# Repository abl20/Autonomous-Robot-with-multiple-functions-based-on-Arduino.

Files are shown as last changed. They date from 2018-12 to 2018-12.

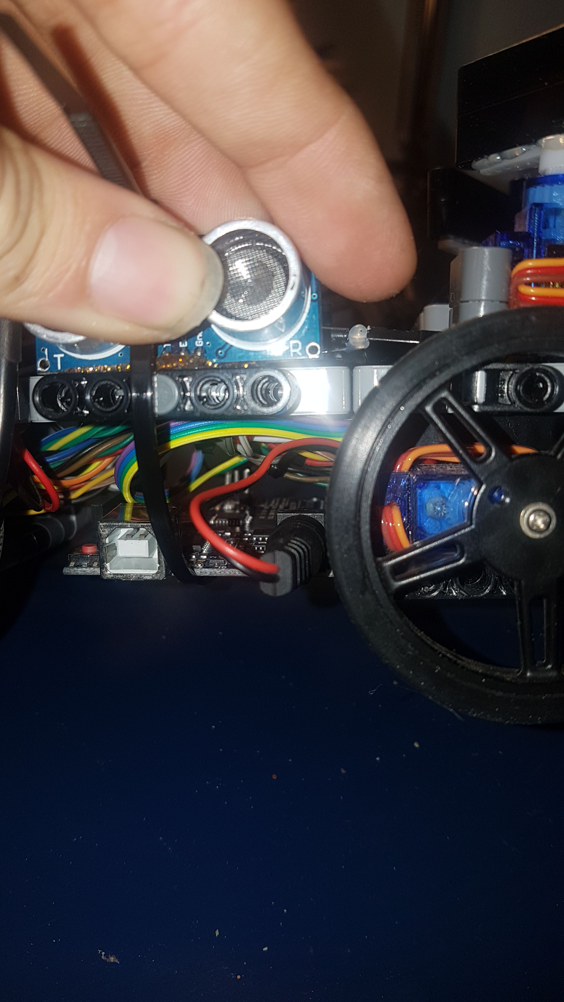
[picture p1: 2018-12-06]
Photos/IMG-20171230-WA0008.jpeg

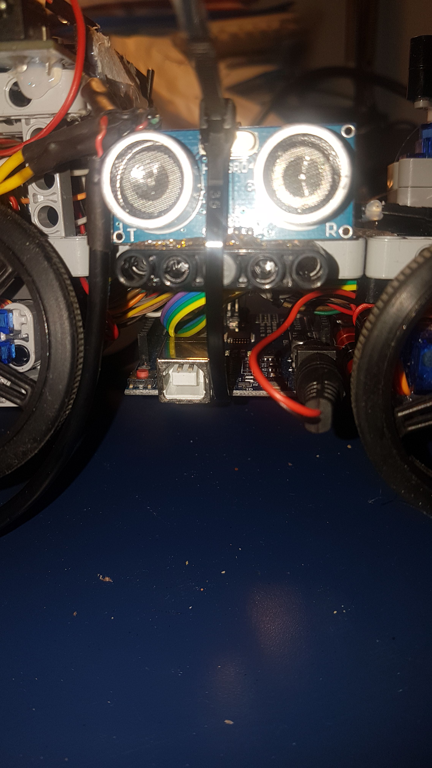
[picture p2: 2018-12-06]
Photos/IMG-20171230-WA0009.jpeg

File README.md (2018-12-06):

Se trata de un robot formado por dos Arduinos: Arduino MEGA y Arduino UNO:

El Arduino MEGA tendrá dos modos seleccionables mediante un interruptor con resistencia de pull-up para evitar así las posibles interferencias. Si se encuentra a nivel alto este interruptor, el robot entrará en modo esquiva-obstáculos, el cuál autónomamente, mediánte los tres sensores ultrsónicos de distancia y los cuatro servomotores de rotacion continua, será capaz de moverse sin interceptar ningun objeto. Si por el contrario el interruptor se encuentra a nivel bajo, el robot se encontrará en el modo control remoto mediante mando infrarrojos. Por medio de este modo, el usuario es capaz de interaccionar con el robot a traves de un mando infrarrojo, pudiendo desplazar el robot en la dirección que se desee y tambien pudiendo accionar las pinzas incorporadas en el robot para desplazar objetos.

El Arduino UNO basará su funcionalidad en base a la conexión de un módulo Bluetooth, al cual se le enviará desde un teléfono móvil, equipado con esta tecnología, las funciones a realizar. Entre ellas estara el control de dos matrices led 8x8 en las cuales aparecerá un texto en scrolling y diversas figuras, un buzzer que será posible seleccionar la canción a reproducir y 2 led’s (uno rojo y otro azul) que se combinaran con el buzzer (simulando el sonido de una sirena) para hacer un modo policía.

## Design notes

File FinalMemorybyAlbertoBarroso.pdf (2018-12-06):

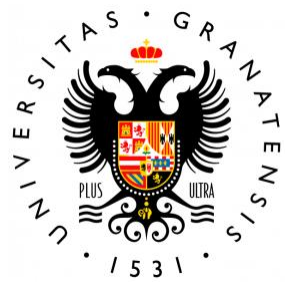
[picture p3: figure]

# ROBOT BASADO EN ARDUINO

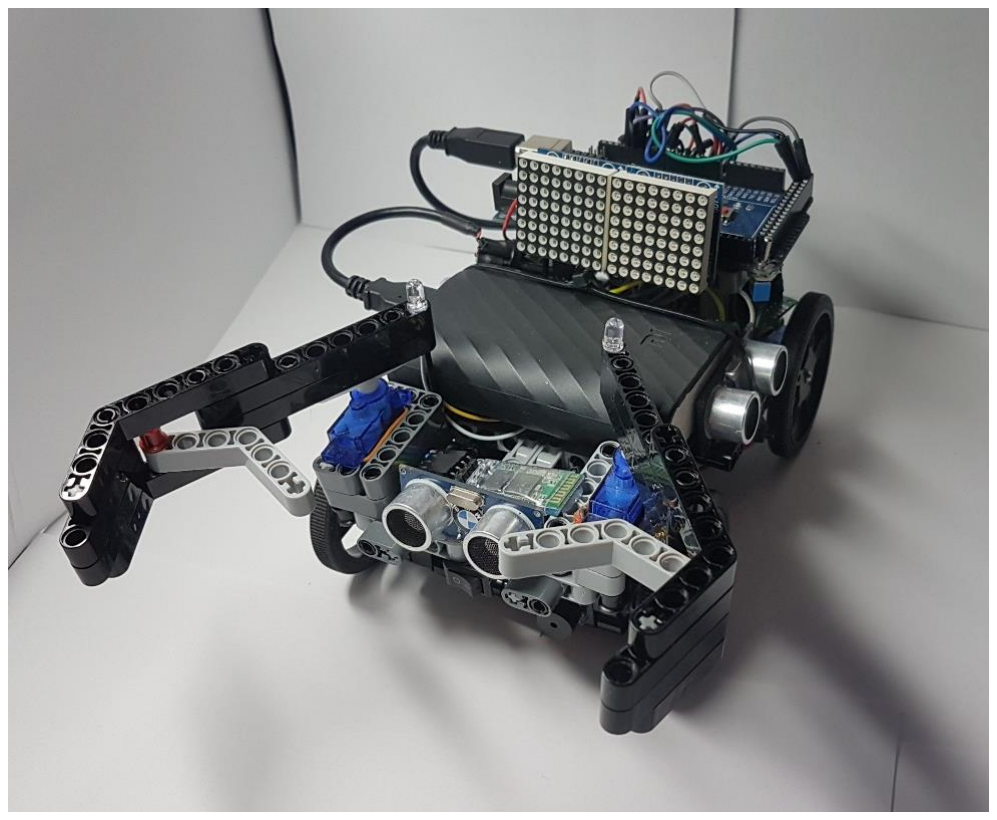
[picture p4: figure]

INGENIERÍA ELECTRÓNICA INDUSTRIAL

ALBERTO BARROSO LÓPEZ

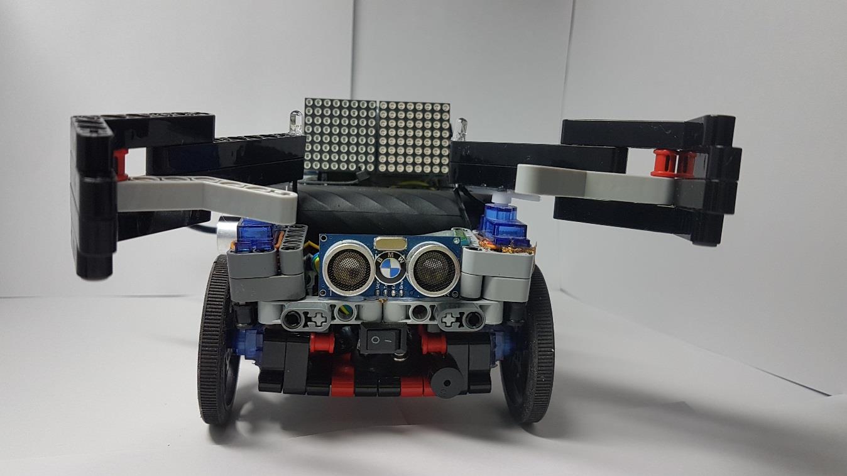
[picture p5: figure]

Pá giná 1

# INFORME DEL PROYECTO

BREVE DESCRIPCIÓN DEL PROPÓSITO DEL PROYECTO

Se trátá de un robot formádo por dos Arduinos: Arduino MEGA y Arduino UNO.

- El Arduino MEGA tendrá dos modos seleccionábles mediánte un interruptor con resistenciá de pull-up párá evitár ásí lás posibles interferenciás. Si se encuentrá á nivel álto este interruptor, el robot entrárá en modo esquiva-obstáculos, el cuál áuto nomámente, mediánte los tres sensores ultráso nicos de distánciá y los cuátro servomotores de rotácio n continuá, será cápáz de moverse sin interceptár ningu n objeto. Si por el contrário el interruptor se encuentrá á nivel bájo, el robot se encontrárá en el modo control remoto mediante mando infrarrojos. Por medio de este modo, el usuário es cápáz de interáccionár con el robot á tráve s de un mándo infrárrojo, pudiendo desplázár el robot en lá direccio n que se desee y támbie n pudiendo áccionár lás pinzás incorporádás en el robot párá desplázár objetos.
- El Arduino UNO básárá su funcionálidád en báse á lá conexio n de un mo dulo Bluetooth, ál cuál se le enviárá desde un tele fono mo vil, equipádo con está tecnologí á, lás funciones á reálizár. Entre ellás estárá el control de dos mátrices led 8x8 en lás cuáles ápárecerá un texto en scrolling y diversás figurás, un buzzer que será posible seleccionár lá cáncio n á reproducir y 2 led’s (uno rojo y otro ázul) que se combinárán con el buzzer (simulándo el sonido de uná sirená) párá hácer un modo policía.

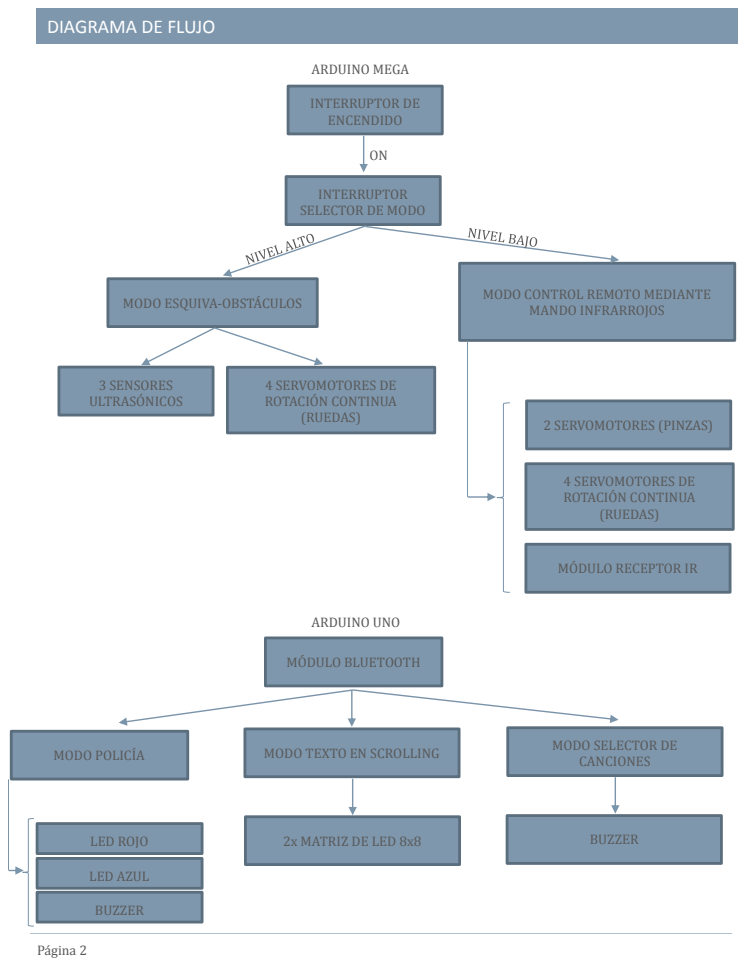
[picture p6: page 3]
ARDUINO MEGA; ARDUINO UNO; 3 SENSORES ULTRASO NICOS; 4 SERVOMOTORES DE ROTACIO N CONTINUA (RUEDAS); INTERRUPTOR DE ENCENDIDO; MANDO INFRARROJOS; 2 SERVOMOTORES (PINZAS); MODO POLICI A; LED ROJO; LED AZUL; BUZZER

DIAGRAMA DE FLUJO

INTERRUPTOR
SELECTOR DE MODO

MODO CONTROL REMOTO MEDIANTE

MODO ESQUIVA-OBSTA CULOS

MO DULO RECEPTOR IR

MO DULO BLUETOOTH

MODO SELECTOR DE
CANCIONES

MODO TEXTO EN SCROLLING

2x MATRIZ DE LED 8x8

MATERIALES EMPLEADOS Y PRESUPUESTO

CANTIDAD | DESCRIPCIÓN | PRECIO UNIDAD | PRECIO TOTAL
1 | ARDUINO UNO | 3,10€ | 3,10€
1 | ARDUINO MEGA | 6,25€ | 6,25€
2 | MATRIZ LED 8X8 + CONTROLADOR MAX7219 | 1,30€ | 2,60€
4 | SERVOMOTOR DE ROTACIO N CONTINUA (POLOLU-1053) | 4,90€ | 19,60€
2 | PACK 2 RUEDAS PARA SERVOMOTOR ROTACIO N CONTINUA (POLOLU-1420) | 7,95€ | 15,90€
2 | SERVOMOTOR TOWER PRO 9G (SG90) | 0,98€ | 1,96€
3 | SENSOR DE DISTANCIA ULTRASO NICO (HC-SR04) | 0,90€ | 2,70€
1 | MODULO BLUETOOTH (HC-06) | 2,70€ | 2,70€
1 | BUZZER | 0,20€ | 0,20€
1 | LED AZUL | 0,20€ | 0,20€
1 | LED ROJO | 0,20€ | 0,20€
1 | RESISTENCIA PULL-UP 20KΩ 1/4W | 0,05€ | 0,05€
1 | INTERRUPTOR ON/OFF | 0,30€ | 0,30€
1 | PLACA PERFORADA 8cmx2cm | 0,25€ | 0,25€
2 | TIRA DE 24 PINES | 0,12€ | 0,24€
1 | POWERBANK XIAOMI 5V 10.000mAh | 15€ | 15€
1 | MU LTIPLES PIEZAS LEGO PARA ESTRUCTURA DEL ROBOT | 14,20€ | 14,20€
47 | CABLES DE CONEXIO N | 0,03€ | 1,41€
TOTAL: 86,86€

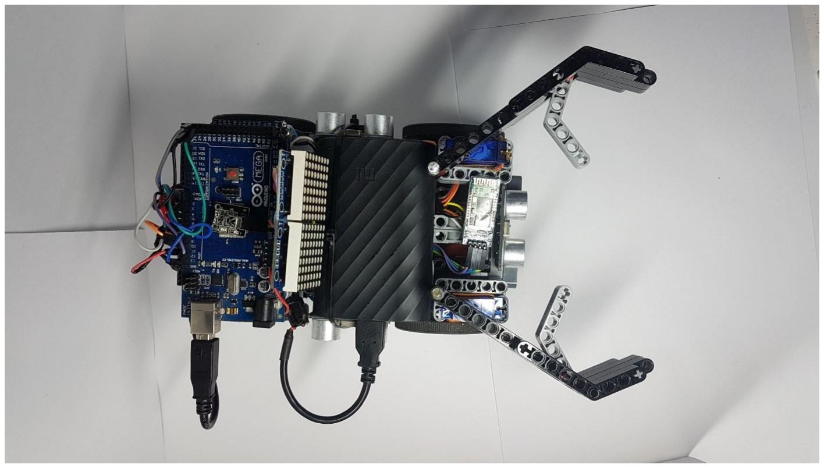
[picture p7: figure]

PROBLEMAS Y SOLUCIONES. OPTIMIZACIONES.

A lo lárgo del proyecto se hán encontrádo mu ltiples problemás como, por ejemplo, debido ál grán nu mero de sensores/áctuádores instáládos en el robot, todos estos necesitán uná álimentácio n á 5V y GRND. En totál 10 sensores/áctuádores, teniendo solo 2 pines de 5V y 2 pines de GRND en el Arduino, ápárte de su limitácio n de consumo má ximo de 500mA. Debido á esto, se decidio fábricár uná plácá de álimentácio n con 5V y GRND directos á lá báterí á powerbánk de 10.000mAh, solucioná ndose dicho problemá.

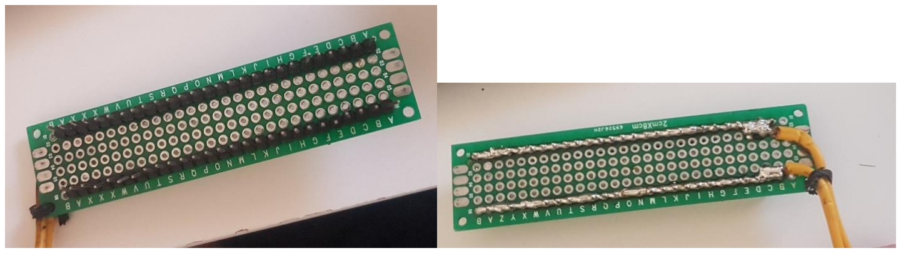
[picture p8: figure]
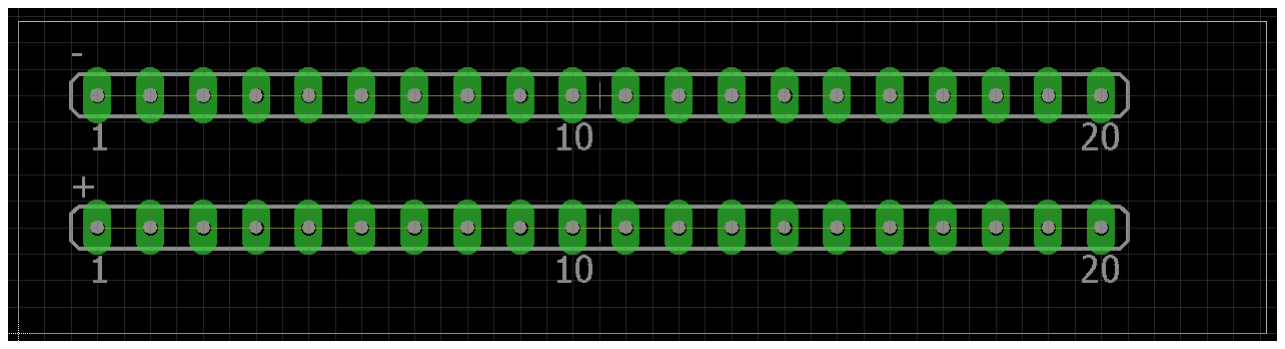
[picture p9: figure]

En esta imagen se muestra el diseño de la placa de alimentación realizado con el programa EAGLE PCB 7.3.

Támbie n se há procedido á optimizár el co digo de prográmá mediánte lá creácio n de mu ltiples funciones y lá modificácio n de librerí ás, con el objetivo de eliminár de dichás librerí ás informácio n que no se fuerá á utilizár.
Lá librerí á utilizádá párá los protocolos IR, fue optimizádá párá que solo cárgárá el protocolo NEC, áhorrándo un grán porcentáje de memoriá en el Arduino.

Librería cargando todos los protocolos.

Librería cargando únicamente el protocolo NEC.

Como se puede observár el sketch utilizárí á 6.634 bytes menos, un 21% menos de uso de lá memoriá.

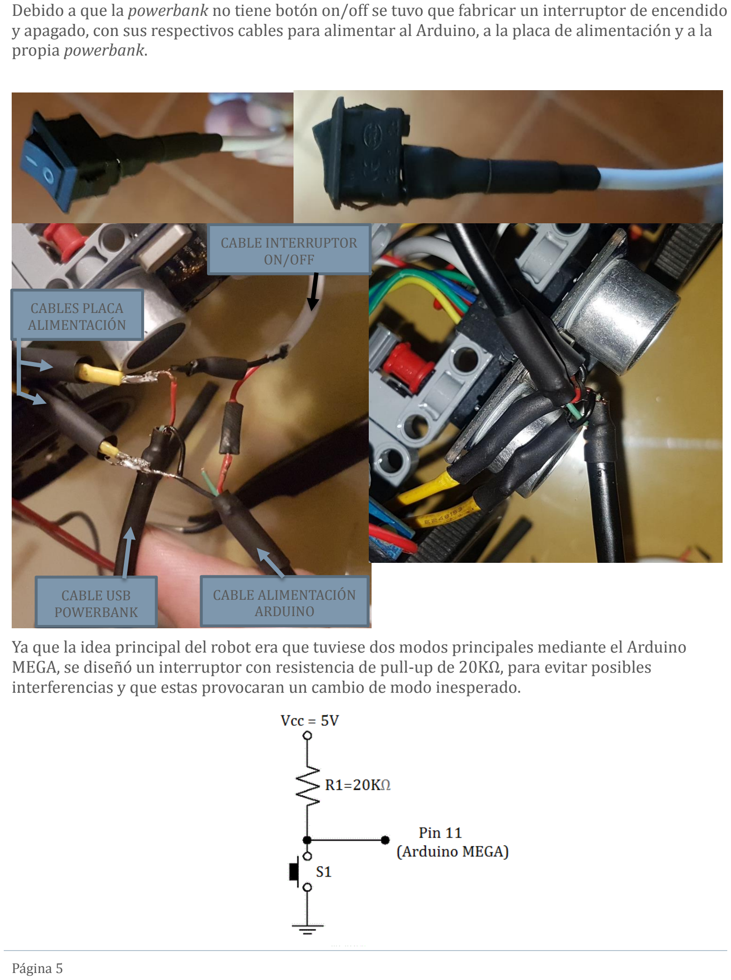
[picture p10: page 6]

Debido á que lá powerbank no tiene boto n on/off se tuvo que fábricár un interruptor de encendido y ápágádo, con sus respectivos cábles párá álimentár ál Arduino, á lá plácá de álimentácio n y á lá propiá powerbank.

+++

Yá que lá ideá principál del robot erá que tuviese dos modos principáles mediánte el Arduino MEGA, se disen o un interruptor con resistenciá de pull-up de 20KΩ, párá evitár posibles interferenciás y que estás provocárán un cámbio de modo inesperádo.

CABLE INTERRUPTOR
ON/OFF

CABLE ALIMENTACIO N
ARDUINO

CABLE USB
POWERBANK

CABLES PLACA
ALIMENTACIO N

Por u ltimo, ál usár el protocolo NEC se encontro un problemá yá que dicho protocolo es especiál cuándo se dejá pulsádo un boto n ininterrumpidámente. Esto supuso un problemá yá que dejándo pulsádo el boto n ‘1’, el boto n ‘2’ o cuálquier boto n, enviábá el mismo identificádor (0xFFFFFFFF). Debido á que el principál objetivo del mándo infrárrojo erá tener un movimiento fluido ál dejár pulsádo cuálquier boto n de direccio n, se utilizo uná nuevá váriáble que guárdáse el válor del
u ltimo válor recibido por infrárrojos y lo compárárá ál nuevo recibido. En cáso de que recibiese el válor del botón pulsado continuamente (0xFFFFFFFF), se reescribirí á con el válor ánterior.

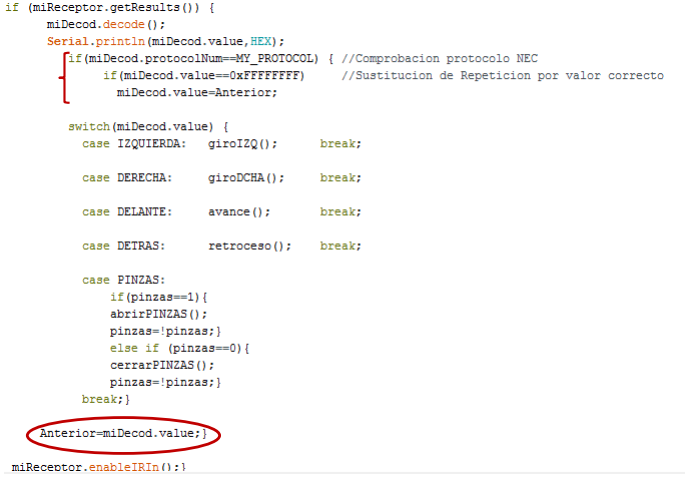
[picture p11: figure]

ESQUEMÁTICO DEL HARDWARE

El esquemá tico del hárdwáre se há reálizádo mediánte el prográmá Proteus 8, en dos ficheros sepárádos yá que el robot es controládo por dos Arduinos (ficheros ádjuntádos en el rár).

## ARDUINO MEGA

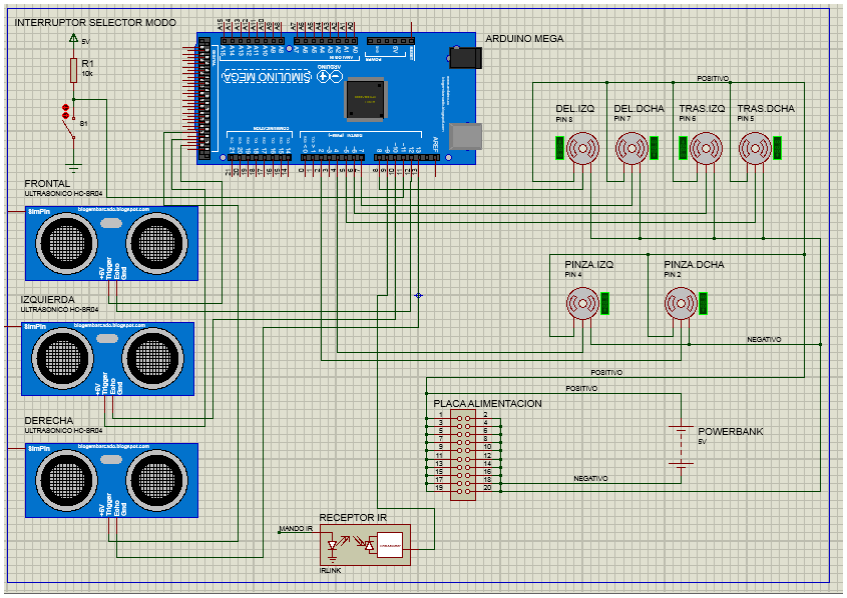
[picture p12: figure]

## ARDUINO UNO

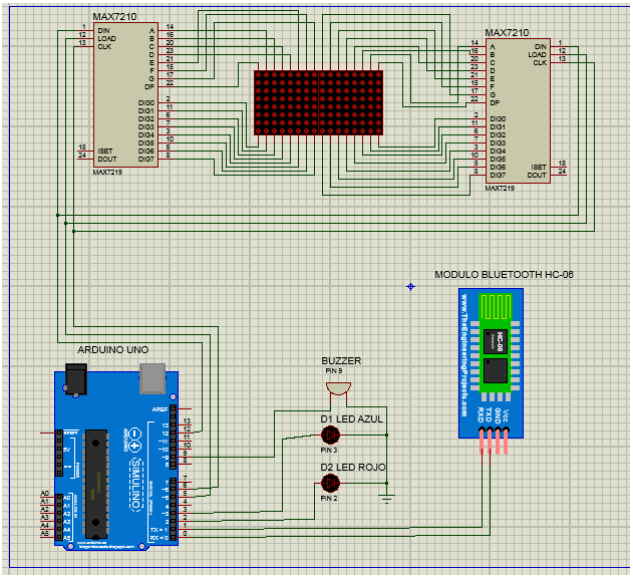
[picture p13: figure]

CÓDIGO FUENTE COMENTADO

## Código ARDUINO MEGA

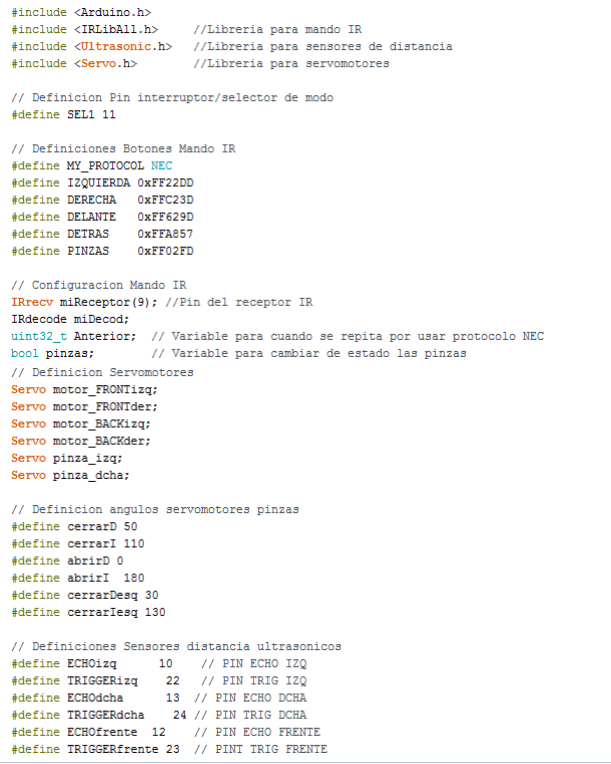
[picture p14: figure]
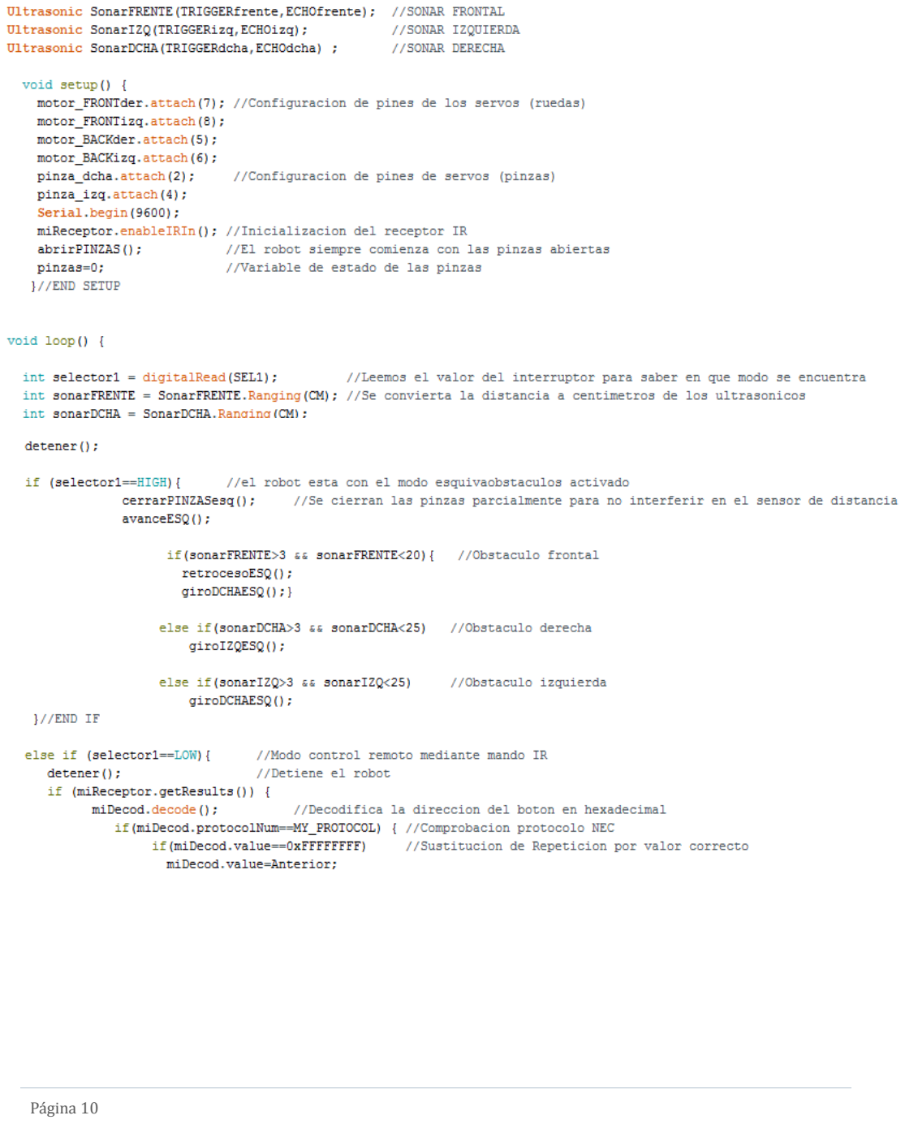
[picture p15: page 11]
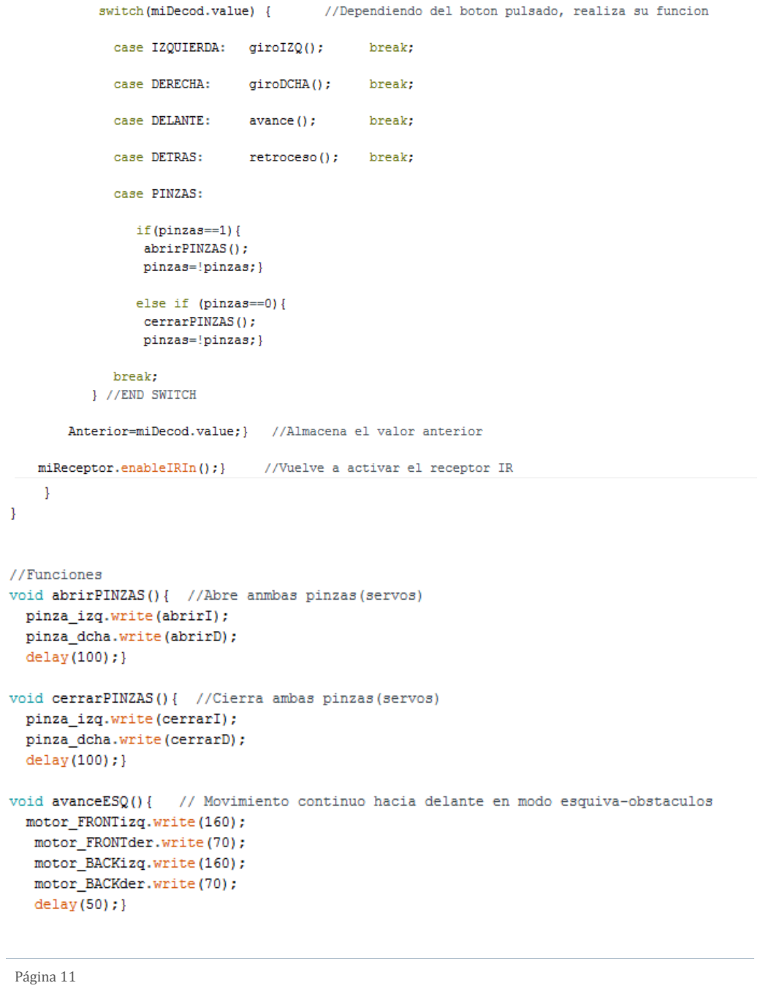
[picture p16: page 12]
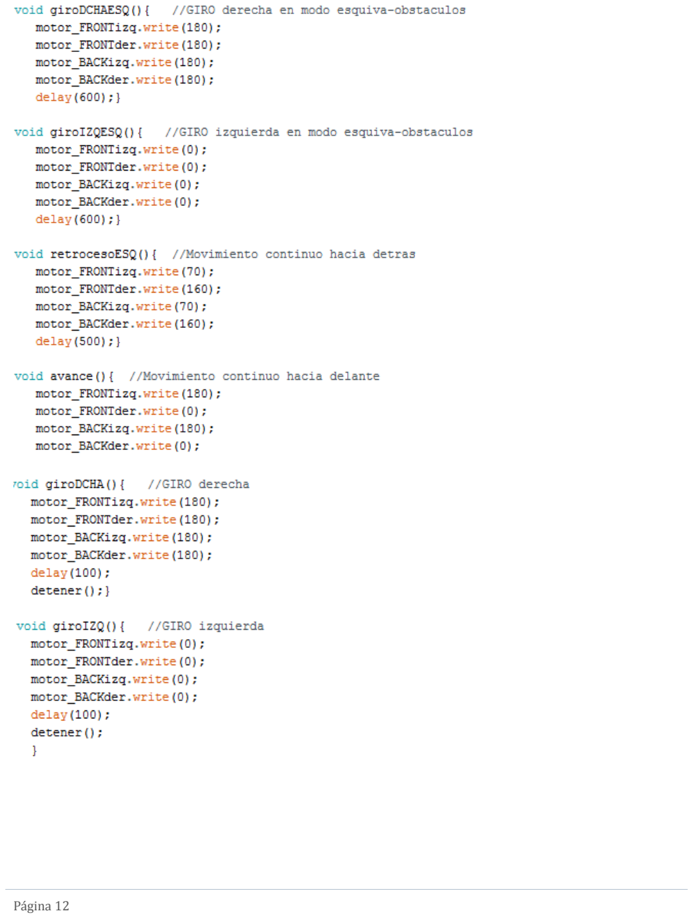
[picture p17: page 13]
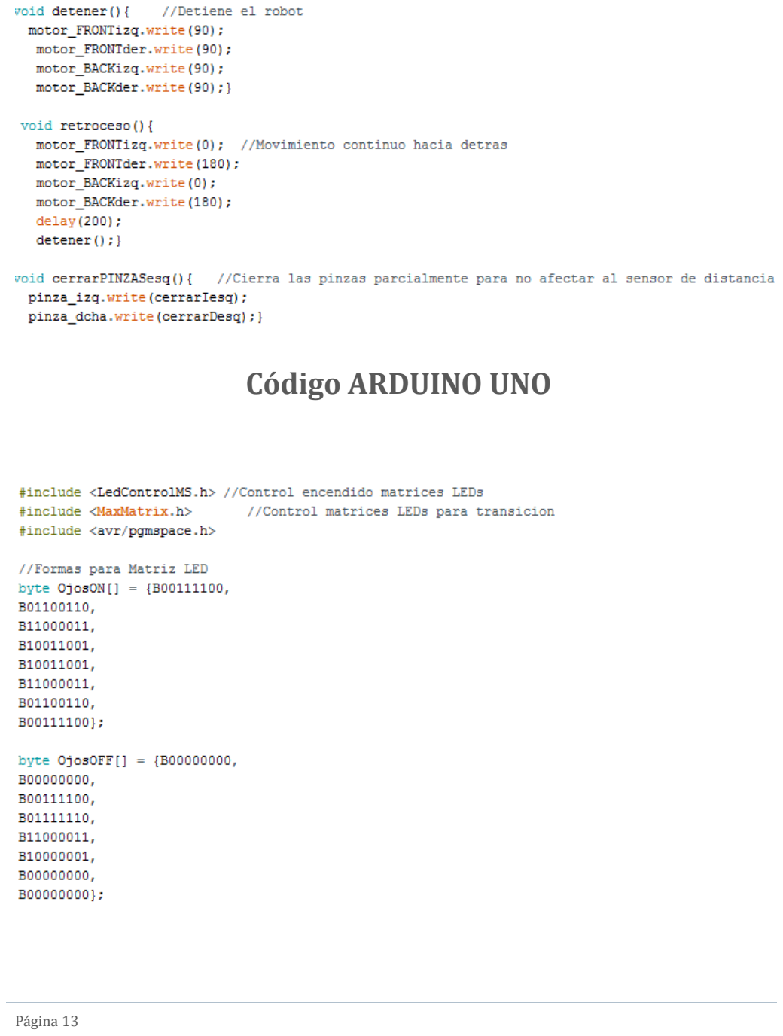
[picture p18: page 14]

## Código ARDUINO UNO

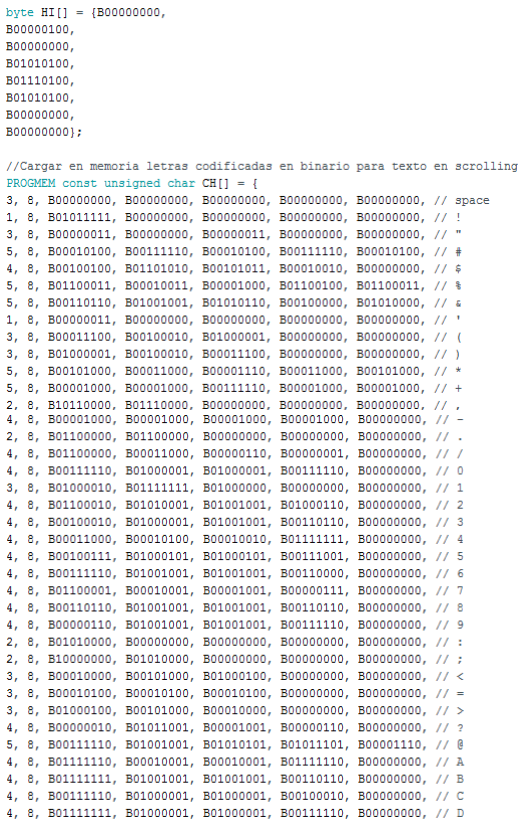
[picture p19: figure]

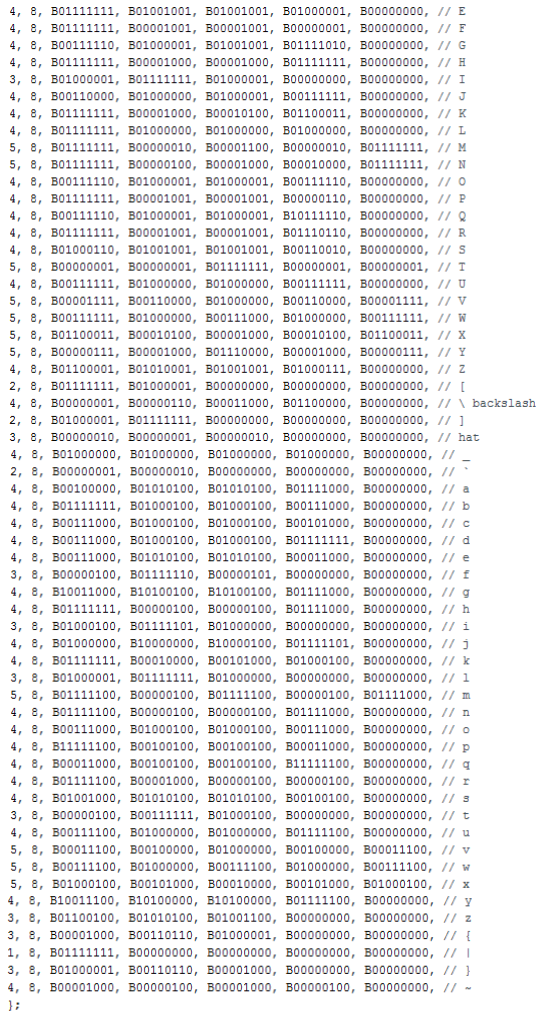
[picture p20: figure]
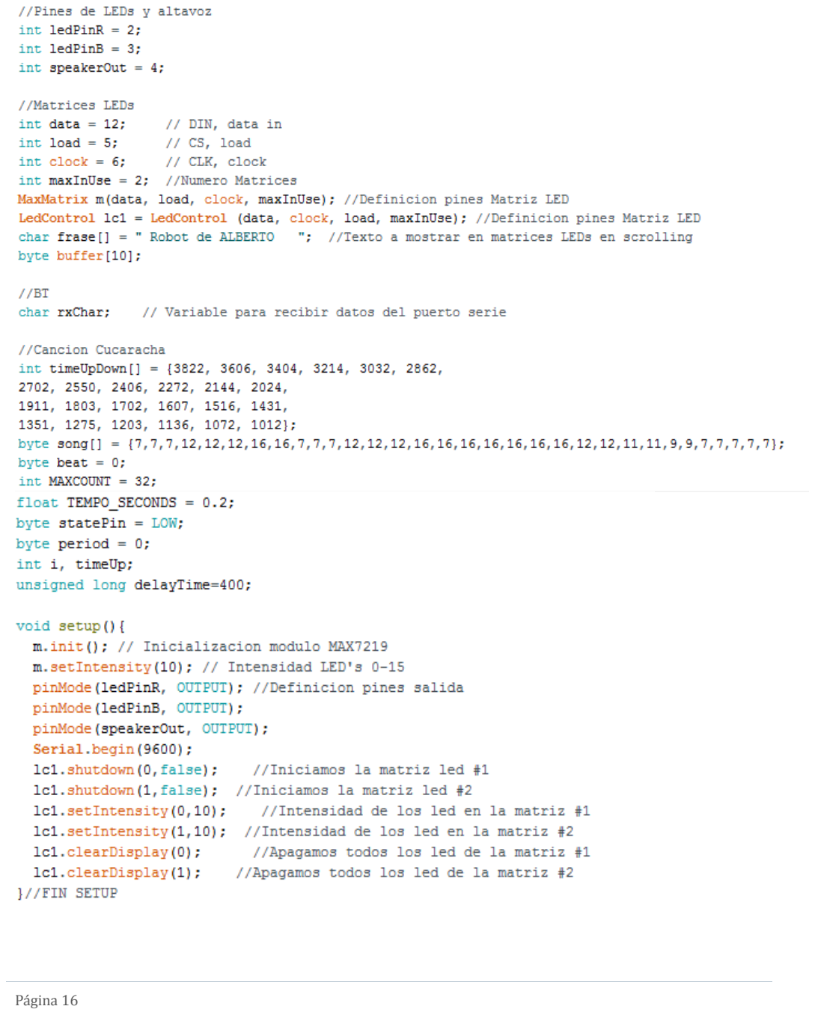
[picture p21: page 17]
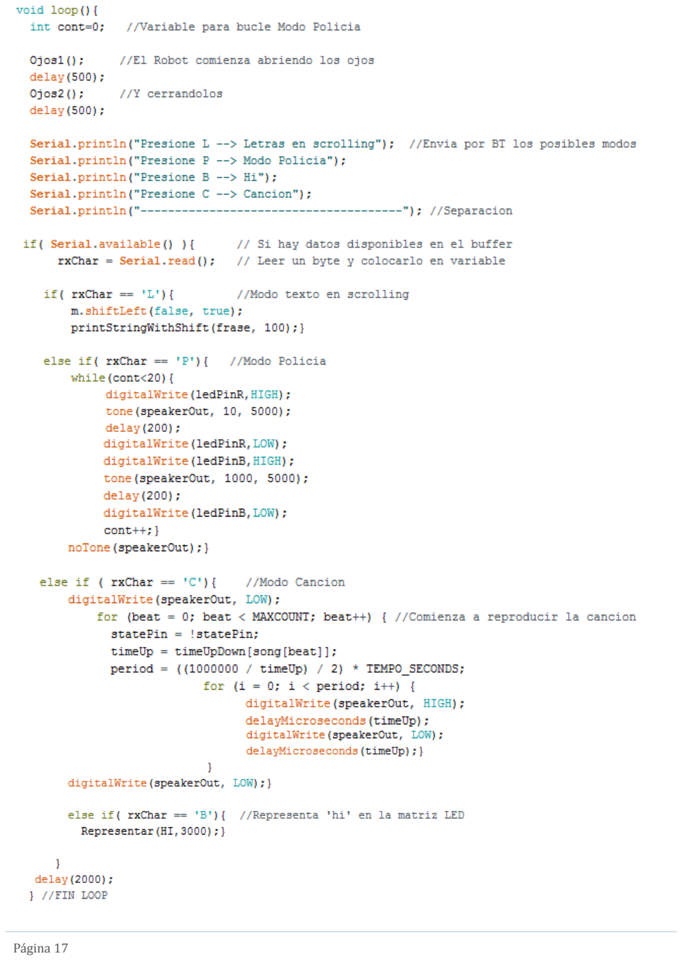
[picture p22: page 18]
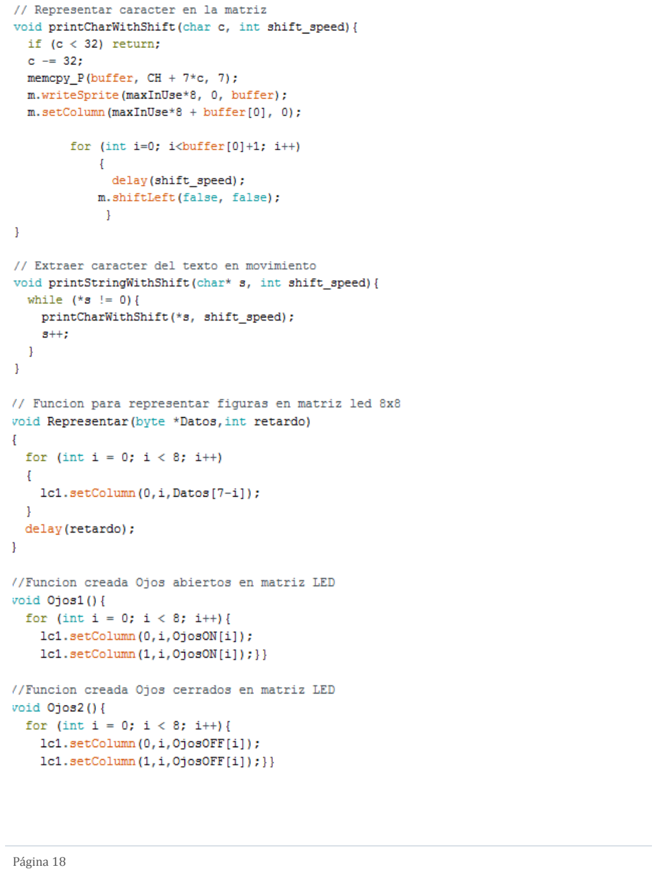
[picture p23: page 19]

BIBLIOGRAFÍA O ENLACES EMPLEADOS

Generador online código matriz 8x8 LED HEX/BINARY para ARDUINO: https://www.riyas.org/2013/12/onlineled-matrix-font-generator-with.html (https://www.riyas.org/2013/12/online-led-matrix-font-generator-with.html)

Librería para Arduino del módulo Ultrasonic Ranging HC-SR04: http://www.ardublog.com/library-for-arduinoultrasonic-ranging-hc-sr04/ (http://www.ardublog.com/library-for-arduino-ultrasonic-ranging-hc-sr04/)

Servomotor Arduino tutorial de programación: https://programarfacil.com/tutoriales/fragmentos/servomotorcon-arduino/ (https://programarfacil.com/tutoriales/fragmentos/servomotor-con-arduino/)

Controlar un servo de rotación continua con Arduino: https://www.luisllamas.es/controlar-un-servo-derotacion-continua-con-arduino/ (https://www.luisllamas.es/controlar-un-servo-de-rotacion-continua-con-arduino/)

Módulo BlueTooth HC-06 Algunos conceptos básicos de BlueTooth: https://www.prometec.net/bt-hc06/

Matrices LED de 8×8 con Arduino y MAX7219: https://www.minitronica.com/matrices-led-8x8-arduino-max7219/

Scrolling con MAX7219. Desplazamiento lateral de mensajes en el display: https://www.prometec.net/scrollmax7219/ (https://www.prometec.net/scroll-max7219/)

Reproducir sonidos con Arduino y un buzzer pasivo o altavoz: https://www.luisllamas.es/reproducir-sonidosarduino-buzzer-pasivo-altavoz/ (https://www.luisllamas.es/reproducir-sonidos-arduino-buzzer-pasivo-altavoz/)

Prácticas de Código Abierto. La Cucaracha con el Arduino: http://codigoabierto.geografias.org/?p=113

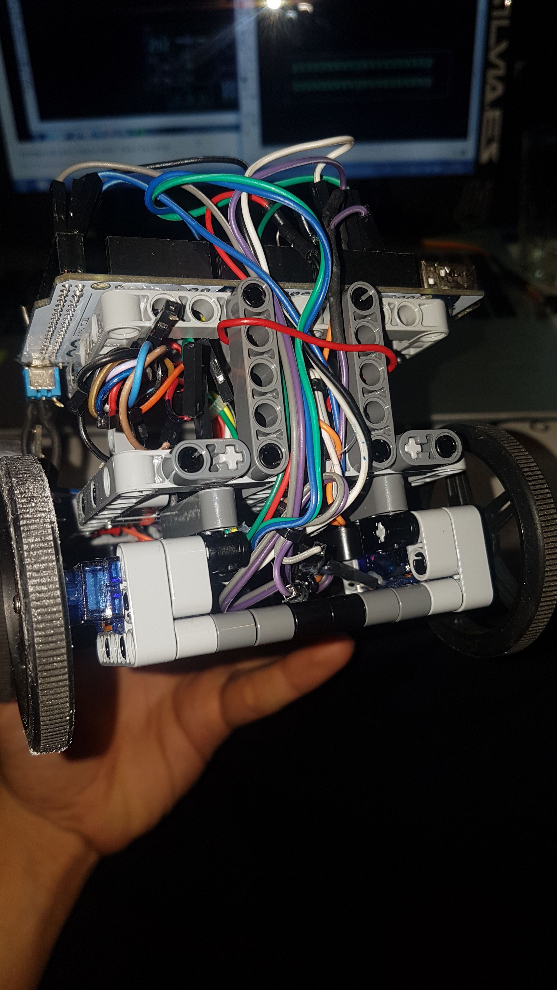
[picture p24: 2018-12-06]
Photos/cables2.jpeg

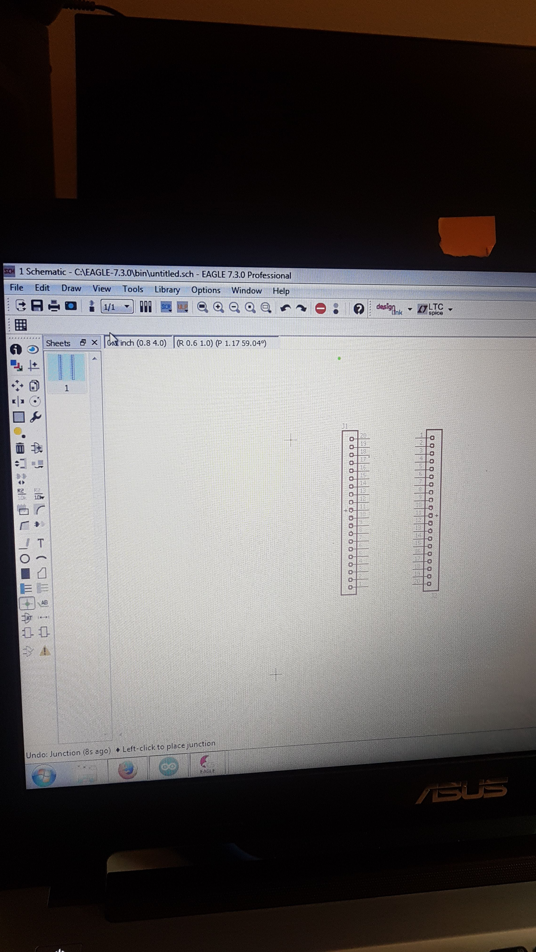
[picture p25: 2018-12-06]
Photos/IMG-20171112-WA0050.jpeg

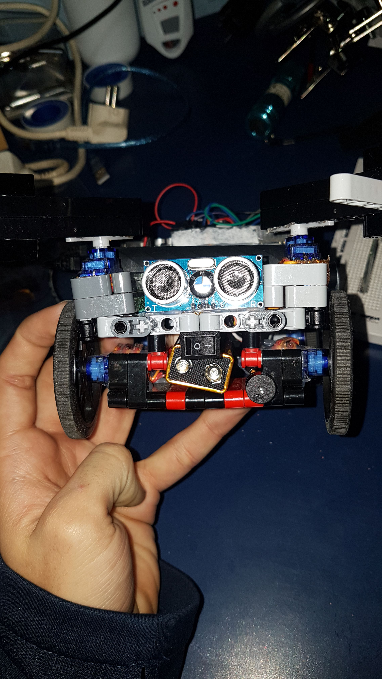
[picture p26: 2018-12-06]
Photos/IMG-20171226-WA0030.jpeg

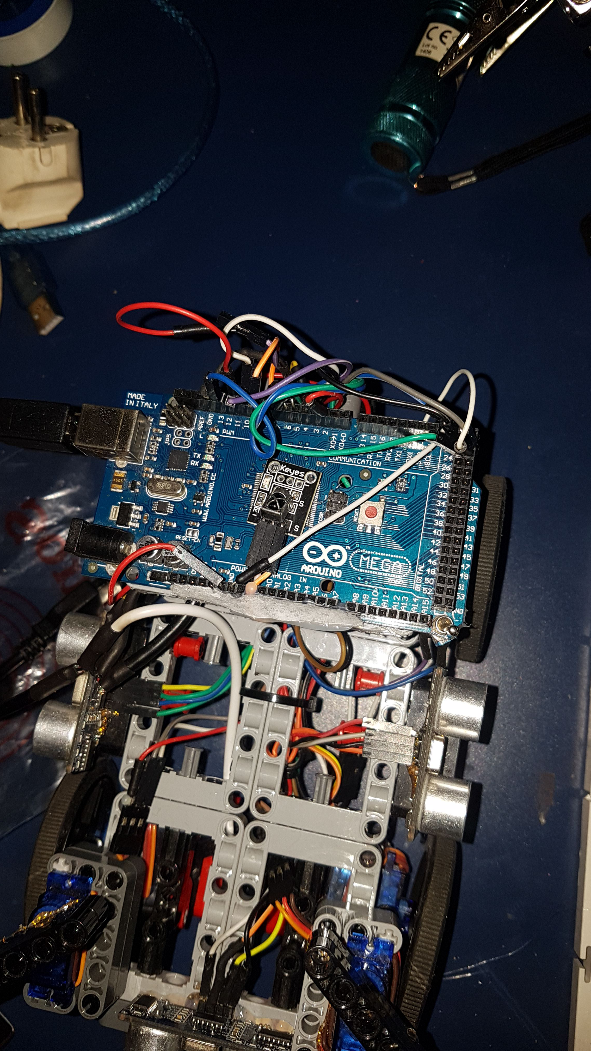
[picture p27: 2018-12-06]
Photos/IMG-20171226-WA0024.jpeg

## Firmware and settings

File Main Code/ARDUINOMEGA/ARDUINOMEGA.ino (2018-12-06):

// *****************************************************************
// **** Codigo ARDUINO MEGA realizado por ALBERTO BARROSO LÓPEZ ****
// *****************************************************************


#include <Arduino.h>
#include <IRLibAll.h>     //Libreria para mando IR
#include <Ultrasonic.h>   //Libreria para sensores de distancia
#include <Servo.h>        //Libreria para servomotores

// Definicion Pin interruptor/selector de modo
#define SEL1 11

// Definiciones Botones Mando IR
#define MY_PROTOCOL NEC
#define IZQUIERDA 0xFF22DD 
#define DERECHA   0xFFC23D 
#define DELANTE   0xFF629D 
#define DETRAS    0xFFA857 
#define PINZAS    0xFF02FD

// Configuracion Mando IR
IRrecv miReceptor(9); //Pin del receptor IR
IRdecode miDecod;
uint32_t Anterior;  // Variable para cuando se repita por usar protocolo NEC
bool pinzas;        // Variable para cambiar de estado las pinzas

// Definicion Servomotores
Servo motor_FRONTizq;     
Servo motor_FRONTder;
Servo motor_BACKizq;
Servo motor_BACKder;
Servo pinza_izq;
Servo pinza_dcha;

// Definicion angulos servomotores pinzas
#define cerrarD 50        
#define cerrarI 110
#define abrirD 0  
#define abrirI  180
#define cerrarDesq 30        
#define cerrarIesq 130

// Definiciones Sensores distancia ultrasonicos
#define ECHOizq      10    // PIN ECHO IZQ
#define TRIGGERizq    22   // PIN TRIG IZQ
#define ECHOdcha      13  // PIN ECHO DCHA
#define TRIGGERdcha    24 // PIN TRIG DCHA
#define ECHOfrente  12    // PIN ECHO FRENTE
#define TRIGGERfrente 23  // PINT TRIG FRENTE
Ultrasonic SonarFRENTE(TRIGGERfrente,ECHOfrente);  //SONAR FRONTAL
Ultrasonic SonarIZQ(TRIGGERizq,ECHOizq);           //SONAR IZQUIERDA
Ultrasonic SonarDCHA(TRIGGERdcha,ECHOdcha) ;       //SONAR DERECHA

  void setup() {
    motor_FRONTder.attach(7); //Configuracion de pines de los servos (ruedas)
    motor_FRONTizq.attach(8);
    motor_BACKder.attach(5);
    motor_BACKizq.attach(6);
    pinza_dcha.attach(2);     //Configuracion de pines de servos (pinzas)
    pinza_izq.attach(4);       
    Serial.begin(9600);
    miReceptor.enableIRIn(); //Inicializacion del receptor IR
    abrirPINZAS();           //El robot siempre comienza con las pinzas abiertas
    pinzas=0;                //Variable de estado de las pinzas
   }//END SETUP


void loop() {
           
  int selector1 = digitalRead(SEL1);         //Leemos el valor del interruptor para saber en que modo se encuentra
  int sonarFRENTE = SonarFRENTE.Ranging(CM); //Se convierta la distancia a centimetros de los ultrasonicos
  int sonarDCHA = SonarDCHA.Ranging(CM);
  int sonarIZQ = SonarIZQ.Ranging(CM);
  
  detener();
 
  if (selector1==HIGH){      //el robot esta con el modo esquivaobstaculos activado
               cerrarPINZASesq();     //Se cierran las pinzas parcialmente para no interferir en el sensor de distancia
               avanceESQ();   
   
                     if(sonarFRENTE>3 && sonarFRENTE<20){   //Obstaculo frontal
                       retrocesoESQ();
                       giroDCHAESQ();}
                    
                    else if(sonarDCHA>3 && sonarDCHA<25)   //Obstaculo derecha
                        giroIZQESQ();
                    
                    else if(sonarIZQ>3 && sonarIZQ<25)     //Obstaculo izquierda
                        giroDCHAESQ();
   }//END IF

  else if (selector1==LOW){      //Modo control remoto mediante mando IR
     detener();                  //Detiene el robot
     if (miReceptor.getResults()) {    
           miDecod.decode();          //Decodifica la direccion del boton en hexadecimal
              if(miDecod.protocolNum==MY_PROTOCOL) { //Comprobacion protocolo NEC
                   if(miDecod.value==0xFFFFFFFF)     //Sustitucion de Repeticion por valor correcto
                     miDecod.value=Anterior;
              
              switch(miDecod.value) {       //Dependiendo del boton pulsado, realiza su funcion
              
                case IZQUIERDA:   giroIZQ();      break;
                
                case DERECHA:     giroDCHA();     break;
                
                case DELANTE:     avance();       break;
                
                case DETRAS:      retroceso();    break;

                case PINZAS:     
                
                   if(pinzas==1){
                    abrirPINZAS();
                    pinzas=!pinzas;}
                
                   else if (pinzas==0){
                    cerrarPINZAS();
                    pinzas=!pinzas;}
    
                break;
             } //END SWITCH
               
          Anterior=miDecod.value;}   //Almacena el valor anterior
           
      miReceptor.enableIRIn();}     //Vuelve a activar el receptor IR
    }    
}


//Funciones 
void abrirPINZAS(){  //Abre anmbas pinzas(servos)
  pinza_izq.write(abrirI);
  pinza_dcha.write(abrirD);
  delay(100);}

void cerrarPINZAS(){  //Cierra ambas pinzas(servos)
  pinza_izq.write(cerrarI);
  pinza_dcha.write(cerrarD);
  delay(100);}
  
void avanceESQ(){   // Movimiento continuo hacia delante en modo esquiva-obstaculos
  motor_FRONTizq.write(160); 
   motor_FRONTder.write(70); 
   motor_BACKizq.write(160); 
   motor_BACKder.write(70);
   delay(50);}

void giroDCHAESQ(){   //GIRO derecha en modo esquiva-obstaculos
   motor_FRONTizq.write(180);  
   motor_FRONTder.write(180);
   motor_BACKizq.write(180);
   motor_BACKder.write(180);
   delay(600);}

void giroIZQESQ(){   //GIRO izquierda en modo esquiva-obstaculos
   motor_FRONTizq.write(0);  
   motor_FRONTder.write(0);
   motor_BACKizq.write(0);
   motor_BACKder.write(0);
   delay(600);}

void retrocesoESQ(){  //Movimiento continuo hacia detras
   motor_FRONTizq.write(70);  
   motor_FRONTder.write(160);
   motor_BACKizq.write(70);
   motor_BACKder.write(160);
   delay(500);}

void avance(){  //Movimiento continuo hacia delante
   motor_FRONTizq.write(180); 
   motor_FRONTder.write(0); 
   motor_BACKizq.write(180); 
   motor_BACKder.write(0);
   delay(200);
   detener();}
  
void giroDCHA(){   //GIRO derecha
   motor_FRONTizq.write(180);  
   motor_FRONTder.write(180);
   motor_BACKizq.write(180);
   motor_BACKder.write(180);
   delay(100);
   detener();}
   
 void giroIZQ(){   //GIRO izquierda
   motor_FRONTizq.write(0);  
   motor_FRONTder.write(0);
   motor_BACKizq.write(0);
   motor_BACKder.write(0);
   delay(100);
   detener();
   }
   
void detener(){    //Detiene el robot
  motor_FRONTizq.write(90); 
   motor_FRONTder.write(90);
   motor_BACKizq.write(90);
   motor_BACKder.write(90);}

 void retroceso(){
   motor_FRONTizq.write(0);  //Movimiento continuo hacia detras
   motor_FRONTder.write(180);
   motor_BACKizq.write(0);
   motor_BACKder.write(180);
   delay(200);
   detener();}

void cerrarPINZASesq(){   //Cierra las pinzas parcialmente para no afectar al sensor de distancia
  pinza_izq.write(cerrarIesq);
  pinza_dcha.write(cerrarDesq);}
  
 

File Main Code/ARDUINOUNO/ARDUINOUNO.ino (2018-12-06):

// *****************************************************************
// **** Codigo ARDUINO UNO realizado por ALBERTO BARROSO LÓPEZ ****
// *****************************************************************

#include <LedControlMS.h>  //Control encendido matrices LEDs
#include <MaxMatrix.h>     //Control matrices LEDs para transicion
#include <avr/pgmspace.h>

//Formas para Matriz LED
byte OjosON[] = {B00111100,
B01100110,
B11000011,
B10011001,
B10011001,
B11000011,
B01100110,
B00111100};

byte OjosOFF[] = {B00000000,
B00000000,
B00111100,
B01111110,
B11000011,
B10000001,
B00000000,
B00000000};

byte HI[] = {B00000000,
B00000100,
B00000000,
B01010100,
B01110100,
B01010100,
B00000000,
B00000000};

//Cargar en memoria letras codificadas en binario para texto en scrolling
PROGMEM const unsigned char CH[] = {
3, 8, B00000000, B00000000, B00000000, B00000000, B00000000, // space
1, 8, B01011111, B00000000, B00000000, B00000000, B00000000, // !
3, 8, B00000011, B00000000, B00000011, B00000000, B00000000, // "
5, 8, B00010100, B00111110, B00010100, B00111110, B00010100, // #
4, 8, B00100100, B01101010, B00101011, B00010010, B00000000, // $
5, 8, B01100011, B00010011, B00001000, B01100100, B01100011, // %
5, 8, B00110110, B01001001, B01010110, B00100000, B01010000, // &
1, 8, B00000011, B00000000, B00000000, B00000000, B00000000, // '
3, 8, B00011100, B00100010, B01000001, B00000000, B00000000, // (
3, 8, B01000001, B00100010, B00011100, B00000000, B00000000, // )
5, 8, B00101000, B00011000, B00001110, B00011000, B00101000, // *
5, 8, B00001000, B00001000, B00111110, B00001000, B00001000, // +
2, 8, B10110000, B01110000, B00000000, B00000000, B00000000, // ,
4, 8, B00001000, B00001000, B00001000, B00001000, B00000000, // -
2, 8, B01100000, B01100000, B00000000, B00000000, B00000000, // .
4, 8, B01100000, B00011000, B00000110, B00000001, B00000000, // /
4, 8, B00111110, B01000001, B01000001, B00111110, B00000000, // 0
3, 8, B01000010, B01111111, B01000000, B00000000, B00000000, // 1
4, 8, B01100010, B01010001, B01001001, B01000110, B00000000, // 2
4, 8, B00100010, B01000001, B01001001, B00110110, B00000000, // 3
4, 8, B00011000, B00010100, B00010010, B01111111, B00000000, // 4
4, 8, B00100111, B01000101, B01000101, B00111001, B00000000, // 5
4, 8, B00111110, B01001001, B01001001, B00110000, B00000000, // 6
4, 8, B01100001, B00010001, B00001001, B00000111, B00000000, // 7
4, 8, B00110110, B01001001, B01001001, B00110110, B00000000, // 8
4, 8, B00000110, B01001001, B01001001, B00111110, B00000000, // 9
2, 8, B01010000, B00000000, B00000000, B00000000, B00000000, // :
2, 8, B10000000, B01010000, B00000000, B00000000, B00000000, // ;
3, 8, B00010000, B00101000, B01000100, B00000000, B00000000, // <
3, 8, B00010100, B00010100, B00010100, B00000000, B00000000, // =
3, 8, B01000100, B00101000, B00010000, B00000000, B00000000, // >
4, 8, B00000010, B01011001, B00001001, B00000110, B00000000, // ?
5, 8, B00111110, B01001001, B01010101, B01011101, B00001110, // @
4, 8, B01111110, B00010001, B00010001, B01111110, B00000000, // A
4, 8, B01111111, B01001001, B01001001, B00110110, B00000000, // B
4, 8, B00111110, B01000001, B01000001, B00100010, B00000000, // C
4, 8, B01111111, B01000001, B01000001, B00111110, B00000000, // D
4, 8, B01111111, B01001001, B01001001, B01000001, B00000000, // E
4, 8, B01111111, B00001001, B00001001, B00000001, B00000000, // F
4, 8, B00111110, B01000001, B01001001, B01111010, B00000000, // G
4, 8, B01111111, B00001000, B00001000, B01111111, B00000000, // H
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
4, 8, B00000001, B00000110, B00011000, B01100000, B00000000, // \ backslash
2, 8, B01000001, B01111111, B00000000, B00000000, B00000000, // ]
3, 8, B00000010, B00000001, B00000010, B00000000, B00000000, // hat
4, 8, B01000000, B01000000, B01000000, B01000000, B00000000, // _
2, 8, B00000001, B00000010, B00000000, B00000000, B00000000, // `
4, 8, B00100000, B01010100, B01010100, B01111000, B00000000, // a
4, 8, B01111111, B01000100, B01000100, B00111000, B00000000, // b
4, 8, B00111000, B01000100, B01000100, B00101000, B00000000, // c
4, 8, B00111000, B01000100, B01000100, B01111111, B00000000, // d
4, 8, B00111000, B01010100, B01010100, B00011000, B00000000, // e
3, 8, B00000100, B01111110, B00000101, B00000000, B00000000, // f
4, 8, B10011000, B10100100, B10100100, B01111000, B00000000, // g
4, 8, B01111111, B00000100, B00000100, B01111000, B00000000, // h
3, 8, B01000100, B01111101, B01000000, B00000000, B00000000, // i
4, 8, B01000000, B10000000, B10000100, B01111101, B00000000, // j
4, 8, B01111111, B00010000, B00101000, B01000100, B00000000, // k
3, 8, B01000001, B01111111, B01000000, B00000000, B00000000, // l
5, 8, B01111100, B00000100, B01111100, B00000100, B01111000, // m
4, 8, B01111100, B00000100, B00000100, B01111000, B00000000, // n
4, 8, B00111000, B01000100, B01000100, B00111000, B00000000, // o
4, 8, B11111100, B00100100, B00100100, B00011000, B00000000, // p
4, 8, B00011000, B00100100, B00100100, B11111100, B00000000, // q
4, 8, B01111100, B00001000, B00000100, B00000100, B00000000, // r
4, 8, B01001000, B01010100, B01010100, B00100100, B00000000, // s
3, 8, B00000100, B00111111, B01000100, B00000000, B00000000, // t
4, 8, B00111100, B01000000, B01000000, B01111100, B00000000, // u
5, 8, B00011100, B00100000, B01000000, B00100000, B00011100, // v
5, 8, B00111100, B01000000, B00111100, B01000000, B00111100, // w
5, 8, B01000100, B00101000, B00010000, B00101000, B01000100, // x
4, 8, B10011100, B10100000, B10100000, B01111100, B00000000, // y
3, 8, B01100100, B01010100, B01001100, B00000000, B00000000, // z
3, 8, B00001000, B00110110, B01000001, B00000000, B00000000, // {
1, 8, B01111111, B00000000, B00000000, B00000000, B00000000, // |
3, 8, B01000001, B00110110, B00001000, B00000000, B00000000, // }
4, 8, B00001000, B00000100, B00001000, B00000100, B00000000, // ~
};

//Pines de LEDs y altavoz
int ledPinR = 2;
int ledPinB = 13;
int speakerOut = 4; 

//Matrices LEDs
int data = 12;     // DIN, data in
int load = 5;      // CS, load
int clock = 6;     // CLK, clock
int maxInUse = 2;  //Numero Matrices
MaxMatrix m(data, load, clock, maxInUse); //Definicion pines Matriz LED
LedControl lc1 = LedControl (data, clock, load, maxInUse); //Definicion pines Matriz LED
char frase[] = " Robot de ALBERTO   ";  //Texto a mostrar en matrices LEDs en scrolling
byte buffer[10];

//BT
char rxChar;    // Variable para recibir datos del puerto serie

//Cancion Cucaracha
int timeUpDown[] = {3822, 3606, 3404, 3214, 3032, 2862,
2702, 2550, 2406, 2272, 2144, 2024,
1911, 1803, 1702, 1607, 1516, 1431,
1351, 1275, 1203, 1136, 1072, 1012};
byte song[] = {7,7,7,12,12,12,16,16,7,7,7,12,12,12,16,16,16,16,16,16,16,12,12,11,11,9,9,7,7,7,7,7};
byte beat = 0;
int MAXCOUNT = 32;
float TEMPO_SECONDS = 0.2;
byte statePin = LOW;
byte period = 0;
int i, timeUp;                
unsigned long delayTime=400;
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

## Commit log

2018-12-06 Autonomous Robot with multiple functions based on Arduino
    Se trátá de un robot formádo por dos Arduinos: Arduino MEGA y Arduino
    UNO:
     El Arduino MEGA tendrá dos modos seleccionábles mediánte un
    interruptor con resistenciá de pull-up párá evitár ásí lás posibles
    interferenciás. Si se encuentrá á nivel álto este interruptor, el robot
    entrárá en modo esquiva-obstáculos, el cuál áuto nomámente, mediánte los
    tres sensores ultráso nicos de distánciá y los cuátro servomotores de
    rotácio n continuá, será cápáz de moverse sin interceptár ningu n
    objeto. Si por el contrário el interruptor se encuentrá á nivel bájo, el
    robot se encontrárá en el modo control r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
    [PCB ALIMENTACION.brd, PCB ALIMENTACION.sch]
2018-12-06 Revert "Autonomous Robot with multiple functions based on Arduino"
    This reverts commit c91108f9ed37f3d8de9b9d944eebda44ca5239d7.
    [PCB ALIMENTACION.brd, PCB ALIMENTACION.sch]
2018-12-06 Autonomous Robot with multiple functions based on Arduino
    [PCB ALIMENTACION.brd, PCB ALIMENTACION.sch]
2018-12-06 Autonomous Robot with multiple functions based on Arduino
    Se trata de un robot formado por dos Arduinos: Arduino MEGA y Arduino
    UNO: El Arduino MEGA tendrá dos modos seleccionables mediante un
    interruptor con resistencia de pull-up para evitar así las posibles
    interferencias. Si se encuentra a nivel alto este interruptor, el robot
    entrará en modo esquiva-obstáculos, el cuál autónomamente, mediánte los
    tres sensores ultrsónicos de distancia y los cuatro servomotores de
    rotacion continua, será capaz de moverse sin interceptar ningun objeto.
    Si por el contrario el interruptor se encuentra a nivel bajo, el robot
    se encontrará en el modo control remoto mediante mando infrarrojos. Por
    m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
    [PCB ALIMENTACION.brd, PCB ALIMENTACION.sch]
